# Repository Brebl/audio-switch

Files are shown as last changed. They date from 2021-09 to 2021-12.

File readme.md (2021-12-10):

# Audio switch   

This is an avr project for selecting one audio signal from multiple input lines (6-port maximum). The project is designed to minimize power consumption by making use of sleep modes, interrupts and internal timers. Other features include multifunction pushbutton, LCD, SPI-communication, automatic detection of audio signals via ADC.\
Objective for this project is to generate amazing sound with minimal distortion.

## Layout

4-port setup with HD44780 display, installed in 3.5" FDD mounting bracket.\
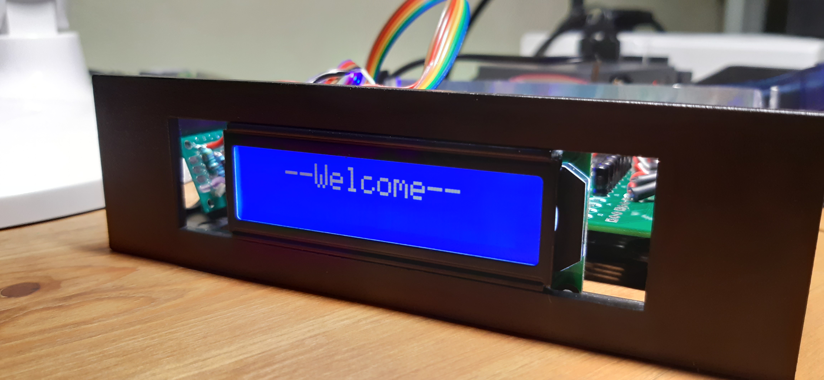
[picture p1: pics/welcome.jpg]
LCD

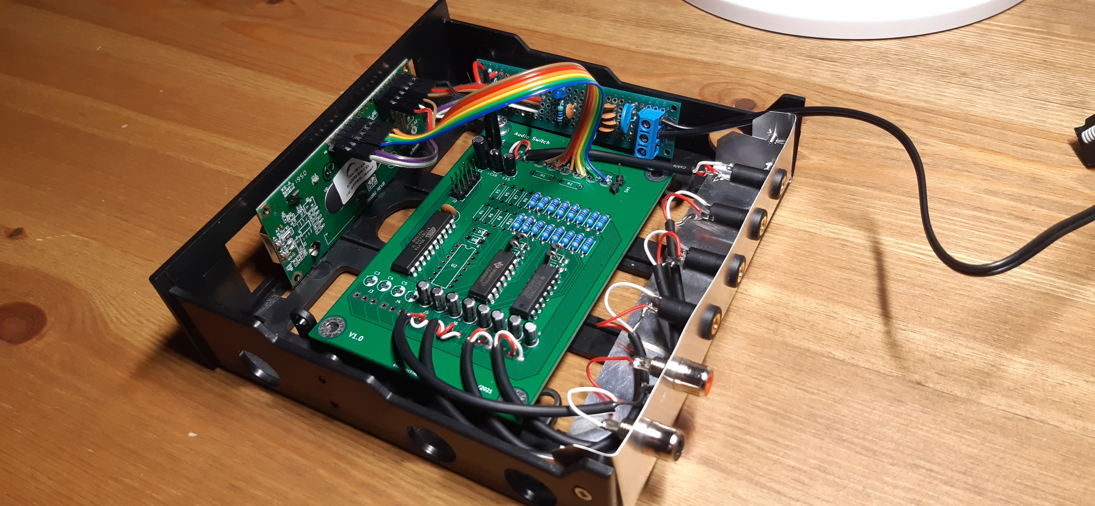
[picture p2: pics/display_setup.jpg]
Test setup
  

## Code / operation

Microcontroller unit detects via analog-to-digital converter what audio lines are receiving signal. MCU sends this information through Serial peripheral interface to the primary MCU and based on input port priority, primary MCU switches on correct input port. Port information is shown in LCD. After 10 secs or so, display turn off to save power. Display is accessed using 4-bit interface. Pushbutton can be used to force certain port open or to switch back to automatic operation.
  
In addition to Master, there's 3 git branches. Each for a different version of this project.
- led_version
- display_version
- automatic_version

To get this running you can use a toolchain
```
avr-libc gcc-avr binutils-avr avrdude
```

For to flash your MCU, run
```shell
make fuses
make flash
```

## Hardware  

Primary MCU is Atmel's Attiny4313 MCU, with internal 128 kHz oscillator. ISP programmer needs to be slowed down because of this low power oscillator. (avrdude -B option) Secondary MCU is Attiny24A. Switching is done by 4066B CMOS Quad Bilateral Switch.
This pcb feature a 10-pin male ISP connector for programming/debugging. Powering this device could be made through USB or with 5V regulator you can use for example 9-volt battery. Board is designed using KiCad software.

### Board

Here's my printed circuit board I ordered from a fabricator pcbway.com\
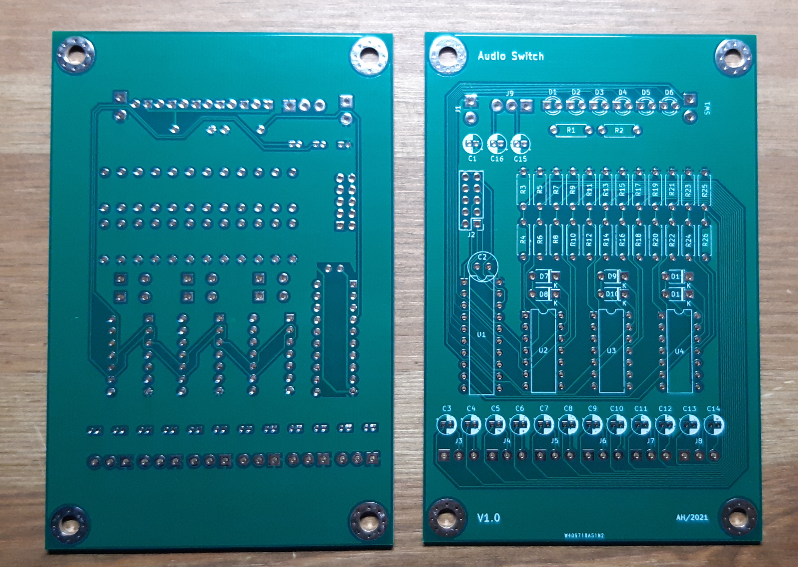
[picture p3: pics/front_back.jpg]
Front


First test setup with "a proper pcb". Works nice.\
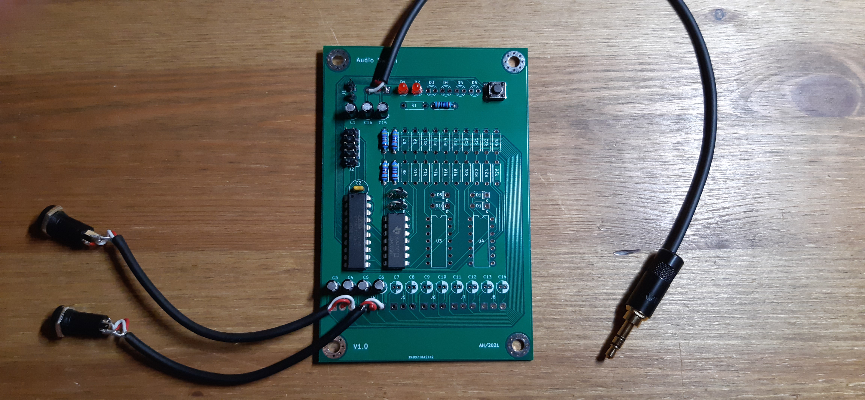
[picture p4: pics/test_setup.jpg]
test-setup


### Electrical charecteristics

Voltage: 5V\
Current: 0,11mA\
Audio connection: max 6x stereo in, 1x stereo out

### Roadmap

- [x] Consept testing with Attiny2313A/4313
- [x] Sleep modes, interrupts
- [x] Simple pushbutton logic
- [x] LED interface
- [x] Schematics
- [x] Design PCB & place order
- [x] Board test setup, sound input/output
- [x] Fabricate enclosure
- [x] Power source
- [x] LCD interface
- [X] ATtiny24A with ADC
- [x] SPI communication 
- [x] Automatic audio signal detection
- [x] Multifunction pushbutton
- [ ] Measure distortion

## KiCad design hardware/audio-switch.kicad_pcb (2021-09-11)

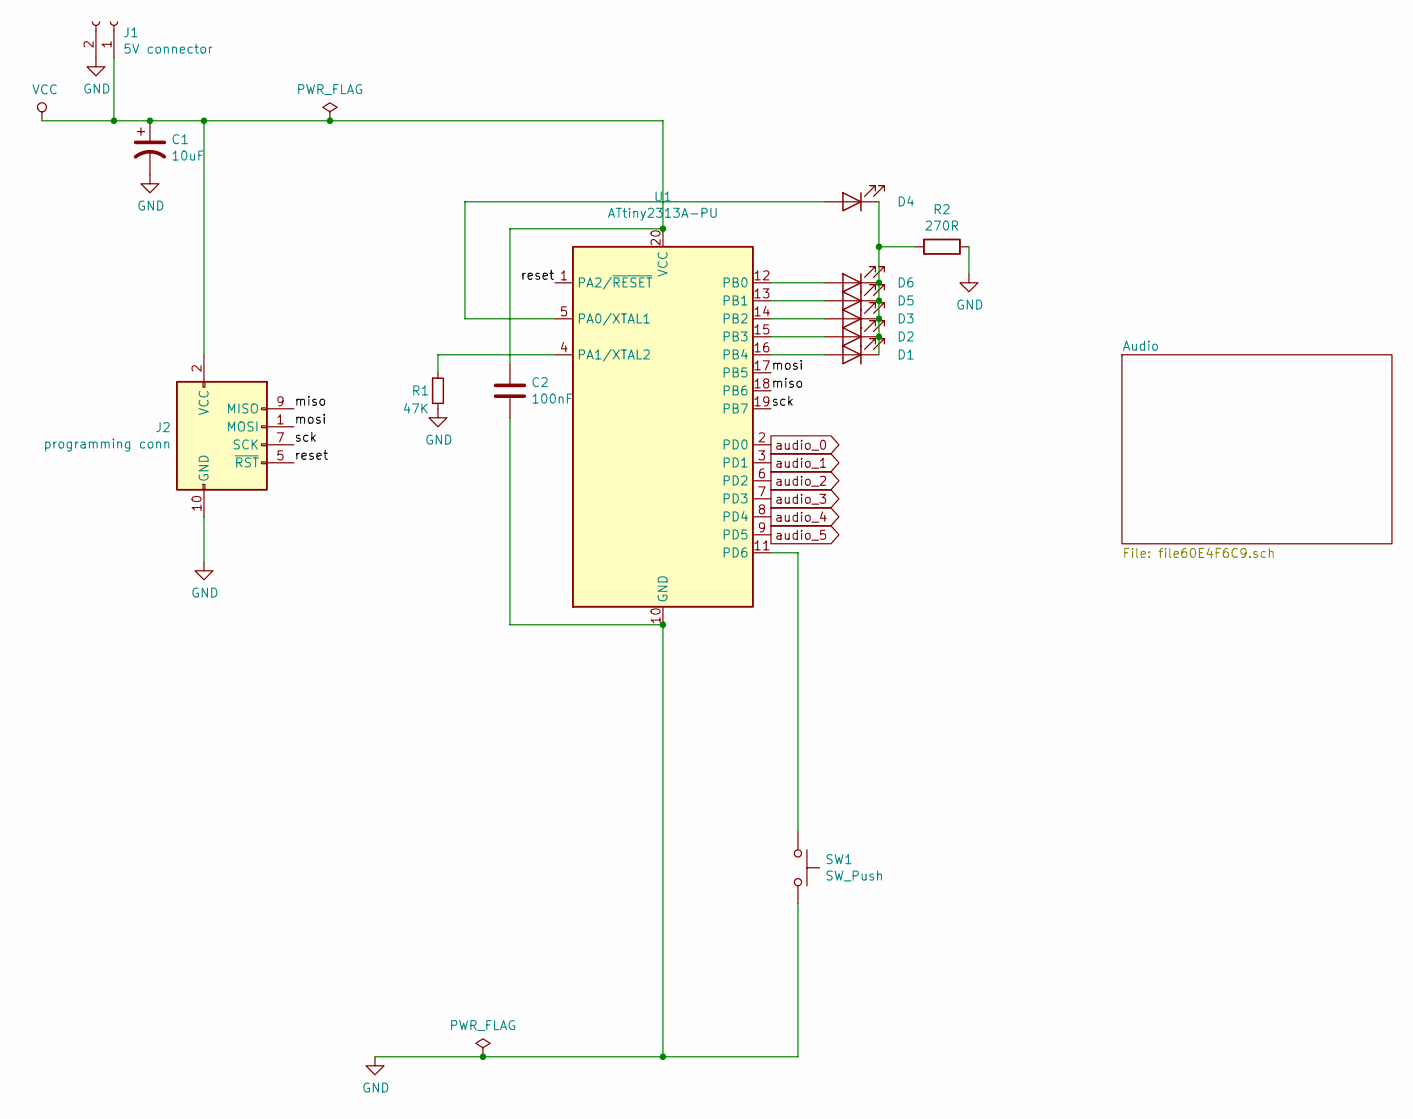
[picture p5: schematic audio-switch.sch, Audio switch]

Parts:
C1: 10uF; CP_Radial_D4.0mm_P1.50mm
C2: 100nF; CP_Radial_D5.0mm_P2.00mm
D1, D2, D3, D4, D5, D6: LED; LED_D3.0mm
J1: 5V connector; SolderWirePad_1x02_P3.81mm_Drill1mm
J2: programming conn; PinHeader_2x05_P2.54mm_Vertical
R1: 47K; R_Axial_DIN0207_L6.3mm_D2.5mm_P7.62mm_Horizontal
R2: 270R; R_Axial_DIN0207_L6.3mm_D2.5mm_P7.62mm_Horizontal
SW1: SW_Push; SolderWirePad_1x02_P3.81mm_Drill1mm
U1: ATtiny2313A-PU; DIP-20_W7.62mm

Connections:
/miso: J2.9 (MISO), U1.18 (PB6)
/mosi: J2.1 (MOSI), U1.17 (PB5)
/reset: J2.5 (~RST), U1.1 (PA2/~RESET)
/sck: J2.7 (SCK), U1.19 (PB7)
GND: C1.2, C2.2, J1.2, J2.4 (GND), J2.6 (GND), J2.8 (GND), J2.10 (GND), R1.2, R2.1, SW1.2, U1.10 (GND); also elsewhere on the board
unnamed: D1.1 (K), D2.1 (K), D3.1 (K), D4.1 (K), D5.1 (K), D6.1 (K), R2.2
unnamed: D1.2 (A), U1.16 (PB4)
unnamed: D2.2 (A), U1.15 (PB3)
unnamed: D3.2 (A), U1.14 (PB2)
unnamed: D4.2 (A), U1.5 (PA0/XTAL1)
unnamed: D5.2 (A), U1.13 (PB1)
unnamed: D6.2 (A), U1.12 (PB0)
unnamed: R1.1, U1.4 (PA1/XTAL2)
unnamed: SW1.1, U1.11 (PD6)
VCC: C1.1, C2.1, J1.1, J2.2 (VCC), U1.20 (VCC); also elsewhere on the board
audio_0: U1.2 (PD0); also elsewhere on the board
audio_1: U1.3 (PD1); also elsewhere on the board
audio_2: U1.6 (PD2); also elsewhere on the board
audio_3: U1.7 (PD3); also elsewhere on the board
audio_4: U1.8 (PD4); also elsewhere on the board
audio_5: U1.9 (PD5); also elsewhere on the board

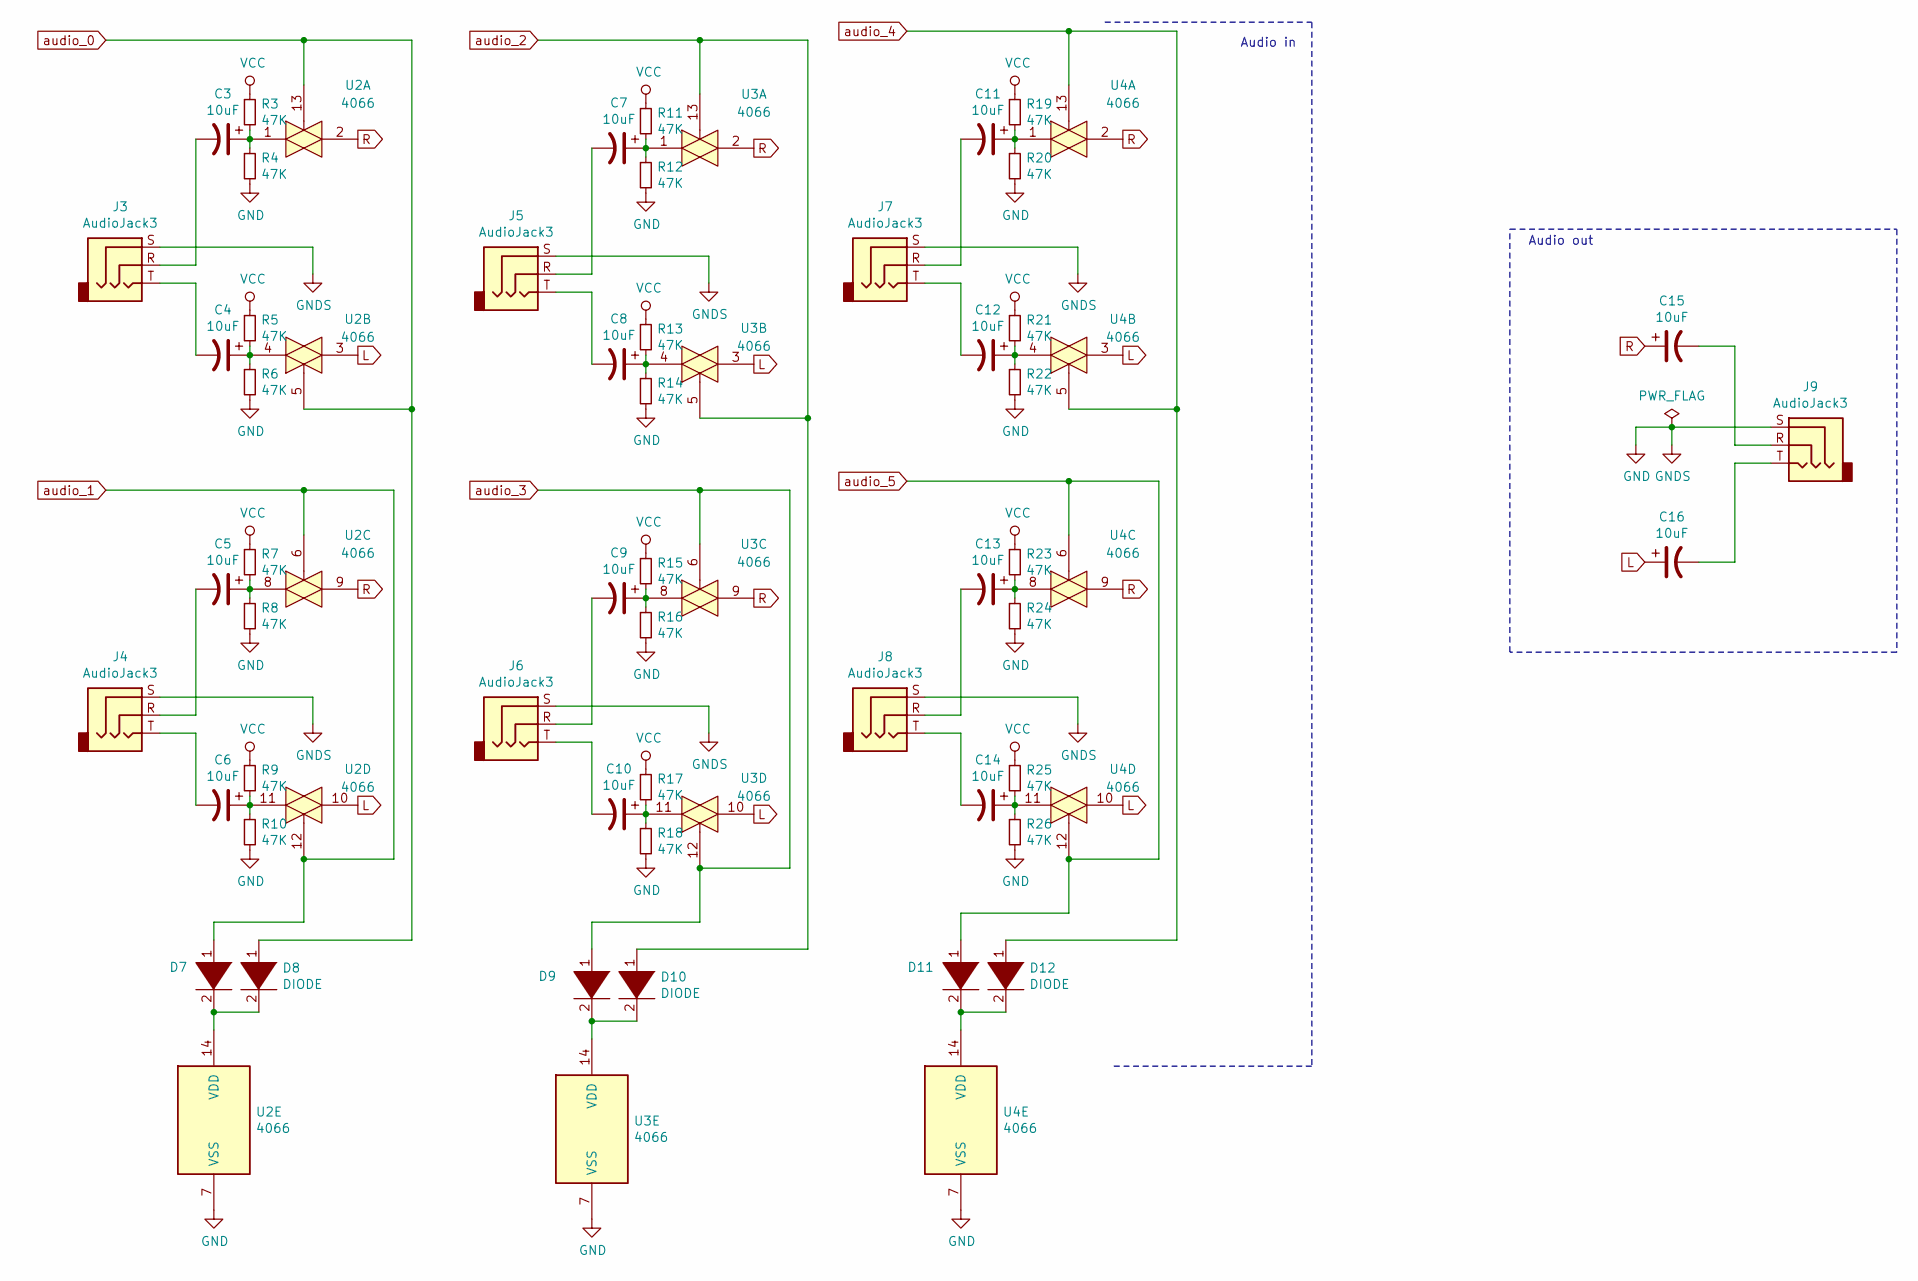
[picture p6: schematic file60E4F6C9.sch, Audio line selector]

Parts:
C3, C4, C5, C6, C7, C8, C9, C10, C11, C12, C13, C14, C15, C16: 10uF; CP_Radial_D4.0mm_P1.50mm
D7, D8, D9, D10, D11, D12: DIODE; D_T-1_P5.08mm_Horizontal
J3, J4, J5, J6, J7, J8, J9: AudioJack3; SolderWirePad_1x03_P3.175mm_Drill1mm
R3, R4, R5, R6, R7, R8, R9, R10, R11, R12, R13, R14, R15, R16, R17, R18, R19, R20, R21, R22, R23, R24, R25, R26: 47K; R_Axial_DIN0207_L6.3mm_D2.5mm_P7.62mm_Horizontal
U2, U3, U4: 4066; DIP-14_W7.62mm

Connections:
GND: J3.S, J4.S, J5.S, J6.S, J7.S, J8.S, J9.S, R4.2, R6.2, R8.2, R10.2, R12.2, R14.2, R16.2, R18.2, R20.2, R22.2, R24.2, R26.2, U2.7 (VSS), U3.7 (VSS), U4.7 (VSS); also elsewhere on the board
L: C16.1, U2.3, U2.10, U3.3, U3.10, U4.3, U4.10
unnamed: C3.1, R3.2, R4.1, U2.1
unnamed: C3.2, J3.R
unnamed: C4.1, R5.2, R6.1, U2.4
unnamed: C4.2, J3.T
unnamed: C5.1, R7.2, R8.1, U2.8
unnamed: C5.2, J4.R
unnamed: C6.1, R9.2, R10.1, U2.11
unnamed: C6.2, J4.T
unnamed: C7.1, R11.2, R12.1, U3.1
unnamed: C7.2, J5.R
unnamed: C8.1, R13.2, R14.1, U3.4
unnamed: C8.2, J5.T
unnamed: C9.1, R15.2, R16.1, U3.8
unnamed: C9.2, J6.R
unnamed: C10.1, R17.2, R18.1, U3.11
unnamed: C10.2, J6.T
unnamed: C11.1, R19.2, R20.1, U4.1
unnamed: C11.2, J7.R
unnamed: C12.1, R21.2, R22.1, U4.4
unnamed: C12.2, J7.T
unnamed: C13.1, R23.2, R24.1, U4.8
unnamed: C13.2, J8.R
unnamed: C14.1, R25.2, R26.1, U4.11
unnamed: C14.2, J8.T
unnamed: C15.2, J9.R
unnamed: C16.2, J9.T
unnamed: D7.2 (A), D8.2 (A), U2.14 (VDD)
unnamed: D9.2 (A), D10.2 (A), U3.14 (VDD)
unnamed: D11.2 (A), D12.2 (A), U4.14 (VDD)
R: C15.1, U2.2, U2.9, U3.2, U3.9, U4.2, U4.9
VCC: R3.1, R5.1, R7.1, R9.1, R11.1, R13.1, R15.1, R17.1, R19.1, R21.1, R23.1, R25.1; also elsewhere on the board
audio_0: D8.1 (K), U2.5, U2.13; also elsewhere on the board
audio_1: D7.1 (K), U2.6, U2.12; also elsewhere on the board
audio_2: D10.1 (K), U3.5, U3.13; also elsewhere on the board
audio_3: D9.1 (K), U3.6, U3.12; also elsewhere on the board
audio_4: D12.1 (K), U4.5, U4.13; also elsewhere on the board
audio_5: D11.1 (K), U4.6, U4.12; also elsewhere on the board

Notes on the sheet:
Audio out
Audio in

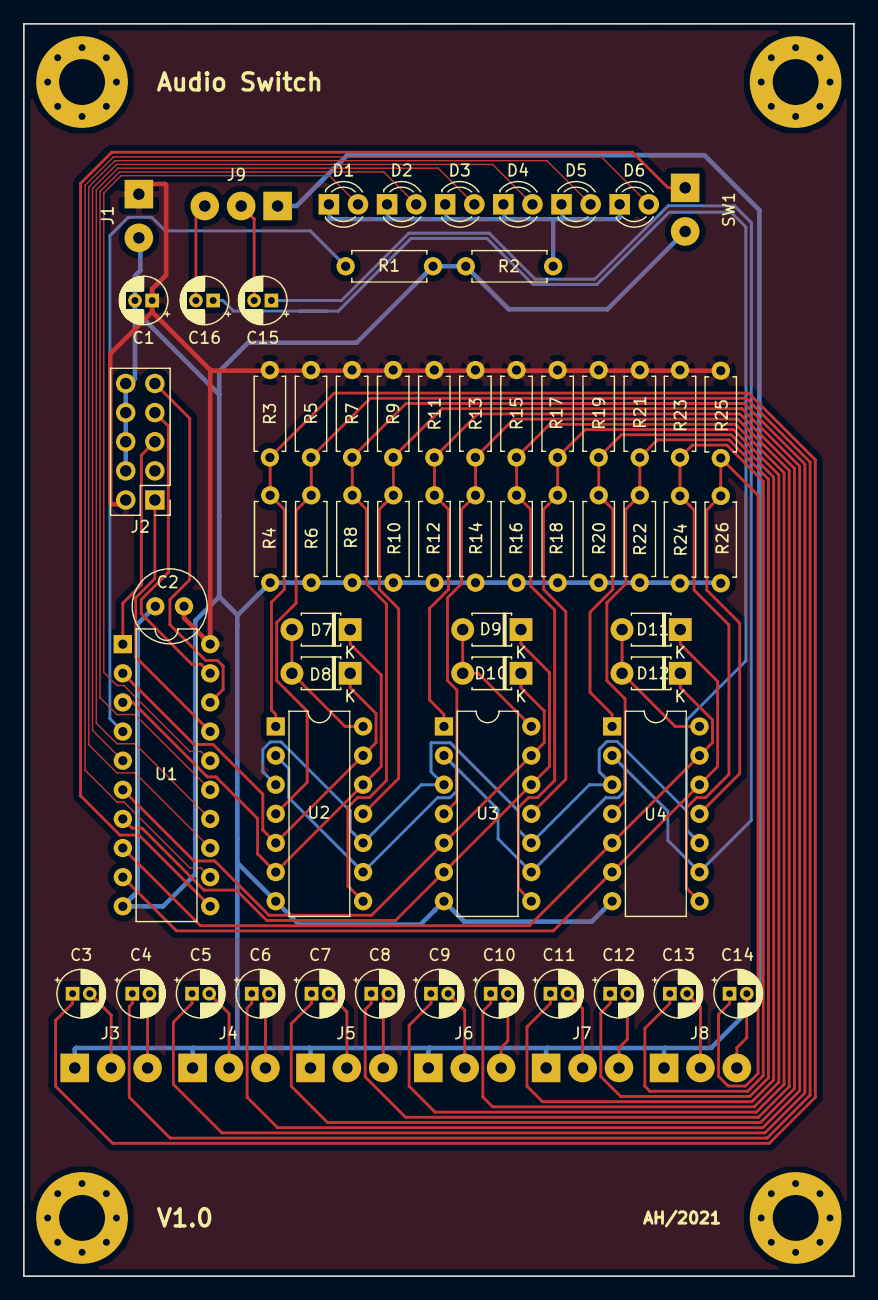
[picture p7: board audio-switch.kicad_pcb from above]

Board: 2 copper layers, 72.4 x 109.2 mm, 68 parts (0 on the bottom side), 52 nets.

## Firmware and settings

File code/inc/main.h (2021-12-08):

#ifndef MAIN_H
#define MAIN_H
#include <avr/io.h>
#include <util/delay.h>
#include <avr/interrupt.h>
#include <avr/eeprom.h>
#include <avr/pgmspace.h>
#include <avr/sleep.h>
#include <avr/wdt.h>
#include <avr/power.h>
#include <stdlib.h>
#include <stdbool.h>

#define INIT    DDRD |= 0x1f; \
                PORTD |= 0x40

#define PUSH_BUTTON PD6
#define PUSH_BUTTON_PORT PIND

//audioport names printed on LCD
#define AUDIO1 "    Computer    "
#define AUDIO2 "      TV        "
#define AUDIO3 "   PlayStation  "
#define AUDIO4 "     Stereos    "
#define AUDIO5 "      VHS       "
#define AUDIO6 "     Input 6    "

//4066B pin configuration
#define TRAN1_PORT PORTD
#define TRAN2_PORT PORTD
#define TRAN3_PORT PORTD
#define TRAN4_PORT PORTD
#define TRAN5_PORT PORTD
#define TRAN6_PORT PORTD

#define TRAN1_PIN PD5
#define TRAN2_PIN PD4
#define TRAN3_PIN PD3
#define TRAN4_PIN PD2
#define TRAN5_PIN PD1
#define TRAN6_PIN PD0

//4066B control
#define TRAN1(X)   ((X) == 0    ? (TRAN1_PORT &= ~(1 << TRAN1_PIN))    : (TRAN1_PORT |= (1 << TRAN1_PIN)))
#define TRAN2(X)   ((X) == 0    ? (TRAN2_PORT &= ~(1 << TRAN2_PIN))    : (TRAN2_PORT |= (1 << TRAN2_PIN)))
#define TRAN3(X)   ((X) == 0    ? (TRAN3_PORT &= ~(1 << TRAN3_PIN))    : (TRAN3_PORT |= (1 << TRAN3_PIN)))
#define TRAN4(X)   ((X) == 0    ? (TRAN4_PORT &= ~(1 << TRAN4_PIN))    : (TRAN4_PORT |= (1 << TRAN4_PIN)))
#define TRAN5(X)   ((X) == 0    ? (TRAN5_PORT &= ~(1 << TRAN5_PIN))    : (TRAN5_PORT |= (1 << TRAN5_PIN)))
#define TRAN6(X)   ((X) == 0    ? (TRAN6_PORT &= ~(1 << TRAN6_PIN))    : (TRAN6_PORT |= (1 << TRAN6_PIN)))

enum Mode {
    automatic,
    manual
};

uint8_t debounce(uint8_t sample);
void init_interrupts();
void change_port(uint8_t new_port);
void change_mode(volatile enum Mode*);

inline void transistors_off()
{
    TRAN1(0);
    TRAN2(0);
    TRAN3(0);
    TRAN4(0);
    TRAN5(0);
    TRAN6(0);
}
#endif

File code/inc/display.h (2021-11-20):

#ifndef DISPLAY_H
#define DISPLAY_H
#include <avr/io.h>	

//data direction register init
#define LCD_INIT    DDRB |= 0x1F; \
                    DDRA |= 0x01

//timing characteristics
#define DELAY_STARTUP _delay_ms(50)
#define DELAY_EN_PULSE _delay_us(1)
#define DELAY_EN_HOLD _delay_us(1)
#define DELAY_CLEAR _delay_ms(2)

//display pin configuration
#define LCD_ENABLE_PORT PORTB
#define LCD_RS_PORT PORTB
#define LCD_D4_PORT PORTB
#define LCD_D5_PORT PORTA
#define LCD_D6_PORT PORTB
#define LCD_D7_PORT PORTB
#define LCD_AK_PORT PORTA

#define LCD_ENABLE_PIN PB3
#define LCD_RS_PIN PB4
#define LCD_D4_PIN PB2
#define LCD_D5_PIN PA0
#define LCD_D6_PIN PB1
#define LCD_D7_PIN PB0
#define LCD_AK_PIN PA1

//display control
#define LCD_EN(X)   ((X) == 0     ? (LCD_ENABLE_PORT &= ~(1 << LCD_ENABLE_PIN))   : (LCD_ENABLE_PORT |= (1 << LCD_ENABLE_PIN)))
#define LCD_RS(X)   ((X) == 0     ? (LCD_RS_PORT &= ~(1 << LCD_RS_PIN))           : (LCD_RS_PORT |= (1 << LCD_RS_PIN)))
#define LCD_D4(X)   ((X) == 0     ? (LCD_D4_PORT &= ~(1 << LCD_D4_PIN))           : (LCD_D4_PORT |= (1 << LCD_D4_PIN)))
#define LCD_D5(X)   ((X) == 0     ? (LCD_D5_PORT &= ~(1 << LCD_D5_PIN))           : (LCD_D5_PORT |= (1 << LCD_D5_PIN)))
#define LCD_D6(X)   ((X) == 0     ? (LCD_D6_PORT &= ~(1 << LCD_D6_PIN))           : (LCD_D6_PORT |= (1 << LCD_D6_PIN)))
#define LCD_D7(X)   ((X) == 0     ? (LCD_D7_PORT &= ~(1 << LCD_D7_PIN))           : (LCD_D7_PORT |= (1 << LCD_D7_PIN)))
#define LCD_AK(X)   ((X) == 0     ? (LCD_AK_PORT &= ~(1 << LCD_AK_PIN))           : (LCD_AK_PORT |= (1 << LCD_AK_PIN)))

#define LCD_EN_PULSE    LCD_EN(1); DELAY_EN_PULSE; LCD_EN(0); DELAY_EN_HOLD

void LCD_init();

// commands:
// 0x01    Clear the display screen (takes 20ms)
// 0x06    Shift the cursor right (e.g. data gets written in an incrementing order, left to right)
// 0x0C    Display on, cursor off
// 0x0E    Display on, cursor blinking
// 0x80    Force the cursor to the beginning of the 1st line
// 0xC0	   Force the cursor to the beginning of the 2nd line
// 0x10    Shift cursor position to the left
// 0x14    Shift cursor position to the right
// 0x18    Shift entire display to the left
// 0x1C    Shift entire display to the right
// 0x38    2 lines, 5x8 matrix, 8-bit mode
// 0x28    2 lines, 5x8 matrix,4-bit mode 
// 0x30    1 line, 8-bit mode
// 0x20    1 line, 4-bit mode	
void LCD_command(uint8_t cmd);
void LCD_char(char chr);
void LCD_animate(char* str);
inline void LCD_string(char* str)
{
    while (*str != '\0') {
        LCD_char(*str++);
    }
}
void LCD_clear_screen();
#endif

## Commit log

2021-05-30 simplify interrupt
2021-06-06 led max count
2021-06-27 hardware add
    [audio-line-selector.kicad_pcb, audio-line-selector.sch, file60E4F6C9.sch]
2021-11-01 corrected push button pin
    [main.h]
2021-11-01 push button interrupt register correct value
    [interrupts.c]
2021-11-11 refactor: buttonpins -> buttonpin
2021-11-20 changed: led -> display
2021-11-20 removed: led
2021-12-05 added: spi sceleton
2021-12-08 added: automatic mode, multifunction button
